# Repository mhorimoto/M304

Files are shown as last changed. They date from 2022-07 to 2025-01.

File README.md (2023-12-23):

# M304
UECS Controller Shield for Arduino MEGA I/F

## 1. PARTS

### 1-1. NIC

DIPタイプのW5500チップを使用したNICを使用する．

Tzt smart electronics USR-ES
https://ja.aliexpress.com/item/4000226162371.html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

### 1-2. LCD

20x4 Parallel connection (秋月コード P-10844)

## 2. Pin Assign

### 2-1. LCD (J1)

| I/O PIN | NAME | LCD PIN |
|:---:|---|:---:|
| | GND  | 1 |
| | Vdd  | 2 |
| | Vo | 3 |
| 37 | RS | 4 |
| 38 | R/W  | 5 |
| 39 | ENA  | 6 |
| 40 | DB0  | 7 |
| 41 | DB1  | 8 |
| 42 | DB2  | 9 |
| 43 | DB3  | 10 |
| 44 | DB4  | 11 |
| 45 | DB5  | 12 |
| 46 | DB6  | 13 |
| 47 | DB7  | 14 |
| | BL+  | 15 |
| | BL-  | 16 |

データピン８ピンすべて接続してある．

### 2-2. Relay OUT (J2)
リレー制御用のポートである．アクティブロー(負論理)である．

| J2 PIN | NAME |I/O PIN |
|:---:|---|:---:|
| 1 | RLY1 | 22 |
| 2 | RLY2 | 23 |
| 3 | RLY3 | 24 |
| 4 | RLY4 | 25 |
| 5 | RLY5 | 26 |
| 6 | RLY6 | 27 |
| 7 | RLY7 | 28 |
| 8 | RLY8 | 29 |
| 9 | Vdd  | +5V  |

リレー制御の自動・手動状態検知のための端子(STAT)はI/O PIN=31である.

|状態|D31の状態|
|:--:|:---:|
|自動| H |
|手動| L |

### 2-3. iM920 Interface (J3)
iM920用のインタフェースで3.3V駆動です.

| J3 PIN | NAME  | I/O PIN |
|:---:|---|:---:|
| 1 | RESET | D6 |
| 2 | BUSY  | D2 |
| 3 | GND | GND |
| 4 | Vcc | 3.3V  |
| 5 | TX | D19(Rx) |
| 6 | RX | D18(Tx) |
| 7 | STATUS| D5 |

### 2-4. GNSS(GPS) Interface (J4)
秋月電子通商のGNSSキット用．

| J4 PIN | NAME  | I/O PIN  |
|:---:|---|:---:|
| 1 | 1PPS  | D4 |
| 2 | RX | D14(Tx3) |
| 3 | TX | D15(Rx3) |
| 4 | GND | GND |
| 5 | Vcc | +5V |

### 2-5. Arrow Switch

アクティブローである．

| I/O PIN | 表示|回路図記号|
|:---:|:---:|:----:|
| 32 | 決定 (SW_ENTER)| SW6 |
| 33 |  ↑ (SW_A) | SW2 |
| 34 |  ↓ (SW_B) | SW3 |
| 35 |  ← (SW_C) | SW4 |
| 36 |  → (SW_D) | SW5 |

### 2-6. 選択
ADCに接続している．ロータリーエンコーダの代わりにADCの出力を得て選択する．

| I/O PIN | 表示 | 回路図記号 |
|:----:|:---:|:---:|
|  A15 | 選択(SELECTOR) | RV2 |

### 2-7. RESET
リセットボタンはArduino MEGAのRESETピンへ直結していると同時にNICのRESETピンにも接続されている．アクティブローである．

### 2-8. SAFEMODE Switch
UECSの初期設定を行う際に必要となるスイッチ．UARDECS_Libraryの既定値である

| I/O PIN | 表示 | 回路図記号 |
|:----:|:---:|:---:|
|  D3  | 初期設定(SAFEMODE) | SW7 |

### 2-9. JA pins (Analog ports)
以下のピン配置で3.3V用8ポート，5V用7ポートがある．
ソフトウェアで入出力の両用に使える．

| XH PIN | 意味 |
|:---:|:---|
| 1 | GND |
| 2 | CPUのAnalog port  |
| 3 | 電源 (3.3V or 5V)  |

コネクタとADCポートの関係

| PORT名 | 電圧 | I/O PIN |
|:-----:|:----:|:---:|
|  JA0  | 3.3V | A0 |
|  JA1  | 3.3V | A1 |
|  JA2  | 3.3V | A2 |
|  JA3  | 3.3V | A3 |
|  JA4  | 3.3V | A4 |
|  JA5  | 3.3V | A5 |
|  JA6  | 3.3V | A6 |
|  JA7  | 3.3V | A7 |
|  JA8  |  5V  | A8 |
|  JA9  |  5V  | A9 |
|  JA10 |  5V  | A10 |
|  JA11 |  5V  | A11 |
|  JA12 |  5V  | A12 |
|  JA13 |  5V  | A13 |
|  JA14 |  5V  | A14 |

### 2-10. JD pins (Digital ports)
以下のピン配置で7ポートある．ソフトウェアで入出力を切り替えられる．

| XH PIN | 意味 |
|:---:|:---|
| 1 | GND |
| 2 | CPUのDigital port  |

コネクタとDIOポートの関係

| PORT名 | I/O PIN |
|:-----:|:---:|
|  JD7  | D7 |
|  JD8  | D8 |
|  JD9  | D9 |
|  JD10 | D10 |
|  JD11 | D11 |
|  JD12 | D12 |
|  JD13 | D13 |

### 2-11. UART (JX2)
外部の装置とUART接続するためのポートが準備されている．
ポート名はJX2．電圧レベルは5V．接続先の送受関係は，2ピンに対象体のRxを3ピンにTxを接続する．

| XH PIN番号 | I/O PIN |
|:---:|:---:|
| 1 | GND |
| 2 | D16 (Tx2) |
| 3 | D17 (Rx2) |

### 2-12. TEST Pad
独自にテストを行う際の独立したDIO pinのパッド．

| Pad名 | I/O PIN |
|:-----:|:---:|
| JD30  | D30 |
| JD48  | D48 |
| JD49  | D49 |

### 2-13. I2C Devices

標準で搭載されているI2Cデバイスは以下の通り．

| Address | 名称 |
|:---:|:---|
| 0x50 | EEPROM AT24C256 |
| 0x68 | RTC DS1307 |

* EEPROM
AT24C256 を使用している．32kBytesの容量がある．
* RTC (Address=0x68)
DS1307を使用してる．(DS1307RTC)

https://stackedit.io/app#

## 3.Software

### 3-1. AT24C256 EEPROM

データの保存を行う他に重要な役割がある．

UECS-IDとMACアドレスを以下のアドレスに記録する．MSB first，Big endianにて記録する．

|  Address | Data |
|:---:|:---|
| 00H〜05H | UECS-ID |
| 06H〜0BH | MAC Address |
| 0CH〜1FH | Reserved |
| 20H〜7FFFH | Data |

* UECS-ID: 10100C00000B
* MAC Address: 02:A2:73:0B:xx:xx

### 3-2. M304_Library

M304_Libraryは，M304を使用する際に初期化やポート名を決定してくれるヘッダファイルと若干の関数がまとめられたファイル．
現状では，Arduino-IDE(arduino-cli)が使用できるディレクトリにコピーして使う．
将来的には，このディレクトリから分離されて，Arduino-IDEなどのライブラリ管理から管理できるようにする．
同時にUARDECS_MEGAとの整合も図る．

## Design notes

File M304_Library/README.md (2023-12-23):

# M304 Common

M304を使用する、汎用ソフトウェアライブラリ

## DISPLAY関連
### PAGE WRITE 機能
20x4のLCD画面をフラットに使用して書き換える。
20x4のメモリエリア(MEM20x4)を全体として使用して、遅いけれど全体を１回で書き込むルーティン。

### LINE WRITE 機能
MEM20x4の中を変更しつつライン単位で出力する。
PAGE WRITEよりも高速。

### CHAR WRITE 機能
MEM20x4の中を変更しつつ文字単位で出力する。
変更する文字の位置(アドレス)を指定して１文字単位で出力する。

## CROSS KEY SWITCH関連
### SIFモード
Start Input Fast モード

関数がコールされたときの入力の状態を返す。

### LIモード
Line Input モード

関数がコールされたら、決定、戻る、のボタンが押されるまで内部で入力処理を行う。

* 数値Aモード

VRによって数値を返す。map()を用いて下限上限を決める事ができる。

* 数値Dモード

上下キーを用いて数値を設定して返す。

## EEPROM関連

## RTC関連

## Ethernet関連
基本的にDHCPによる自動設定にする。IPアドレスなどのネットワーク情報はLCD画面に表示することが出来るのでDHCPで受信しても大丈夫。
* Broadcastに関しては、ネットワーク内でBroadcastするようにした。
具体的には、192.168.11.0/24のネットワークでは、192.168.11.255/24がブロードキャストアドレスとして適用する。また、172.16.0.0/16の場合には、172.16.255.255/16をブロードキャストアドレスとして適用する。他のケースもbitmaskに合わせて正確なブロードキャストを行う。

DNS
## GPS/GNSS関連

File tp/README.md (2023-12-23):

# Test Programs (tp)

M304 を単体動作させて機能を確認するためのプログラムです．

## tp001

LCDの動作確認を行うプログラム

## tp002

矢印キーおよび選択ボリュームの動作確認を行うプログラム

## tp003

選択ボリュームの出力値 0〜1023 を 0〜255 にまるめて，その値を元にリレーを動作させる．
すなわち，8個あるリレーをボリューム出力値に合わせてMake/Breakさせる．

## tp004

I2C EEPROMの動作確認を行うプログラム．  
実体は，ardeeprom (https://github.com/mhorimoto/ardeeprom.git) である．

## tp005

Ethernetを用いたLAN接続動作確認を行うプログラム

http://www.holly-linux.com/whoami/

へアクセスして，自局のIPアドレスを表示します．DHCPサービスでローカルIPが必要になります．

## tp006

RTCを用いた時刻表示プログラム

* DS1307RTC Library (https://github.com/PaulStoffregen/DS1307RTC.git)
* Time Library (https://github.com/PaulStoffregen/Time)

## tp007

GPSを用いた時刻表示ブログラム  
GPSで得られた時刻とRTCで得られた時刻を並行表示する．

## tp100

一連のTPシリーズとは異なりTinyGSMを用いてLTE回線経由でインターネットアクセスする．

* TinyGSM Library (https://github.com/vshymanskyy/TinyGSM.git)

WebClientを試す．

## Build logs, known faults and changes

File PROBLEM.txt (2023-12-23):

問題点

# CrossSwitch
* CrossSwitchのチャタリングがある。ソフトウェアで吸収すべきかもしれないが、
ソフトウェアの容易さと容量問題からCRによる簡易なチャタリング防止回路が欲しい。

* VRによる連続量入力は、ロータリーエンコーダにすべきだった。
VRの初期位置により既存入力値が変動してしまうのはよくない。
例えば、0〜255の範囲における既存入力値が50だったとして、VRの位置が
右に振り切っていた場合、入力値選択の開始は255から始まってしまう。
50から右に回すと増えていき、左に回すと減る。という人間的な感覚に追従できない。
そのため、CrossSwitchのUP/DOWNボタンを使うことになる。50から100へ変更する時、
50回ボタンを押すのは辛いので、連続量入力にしたい。

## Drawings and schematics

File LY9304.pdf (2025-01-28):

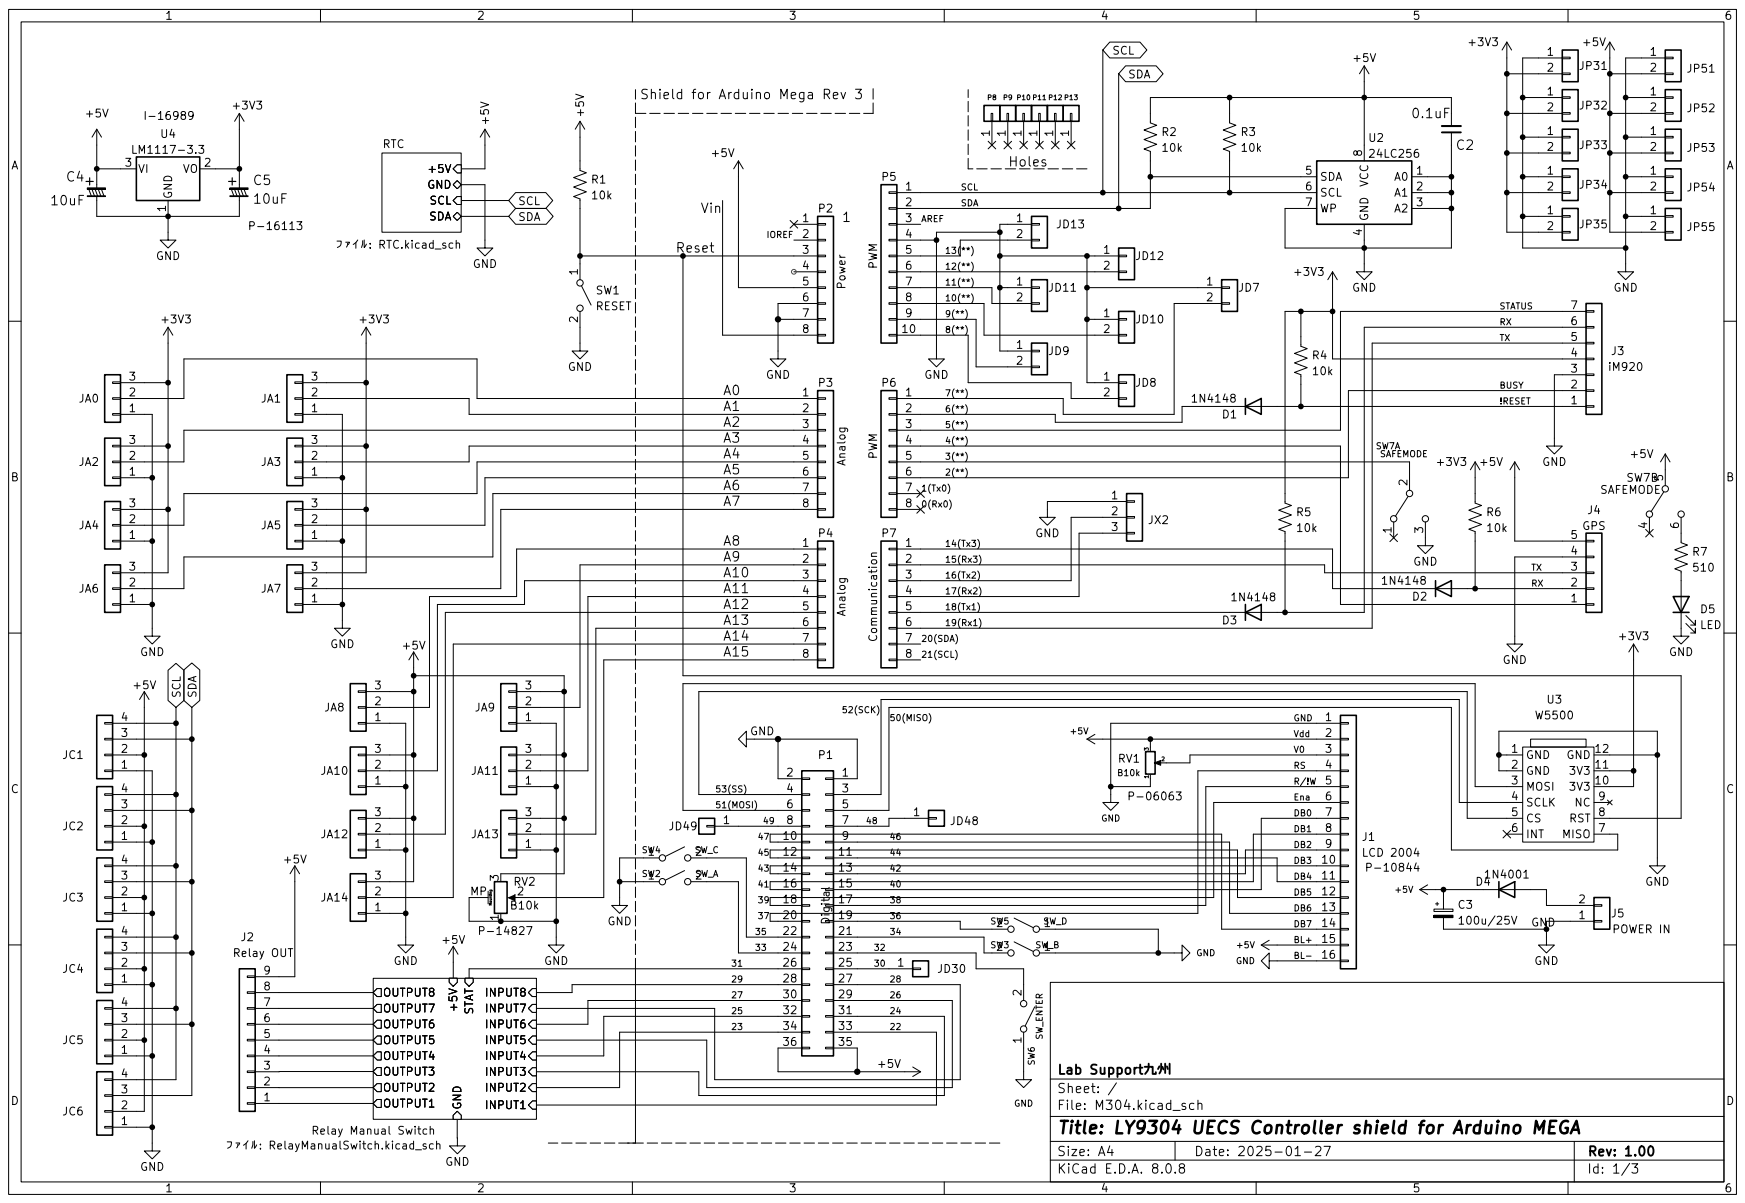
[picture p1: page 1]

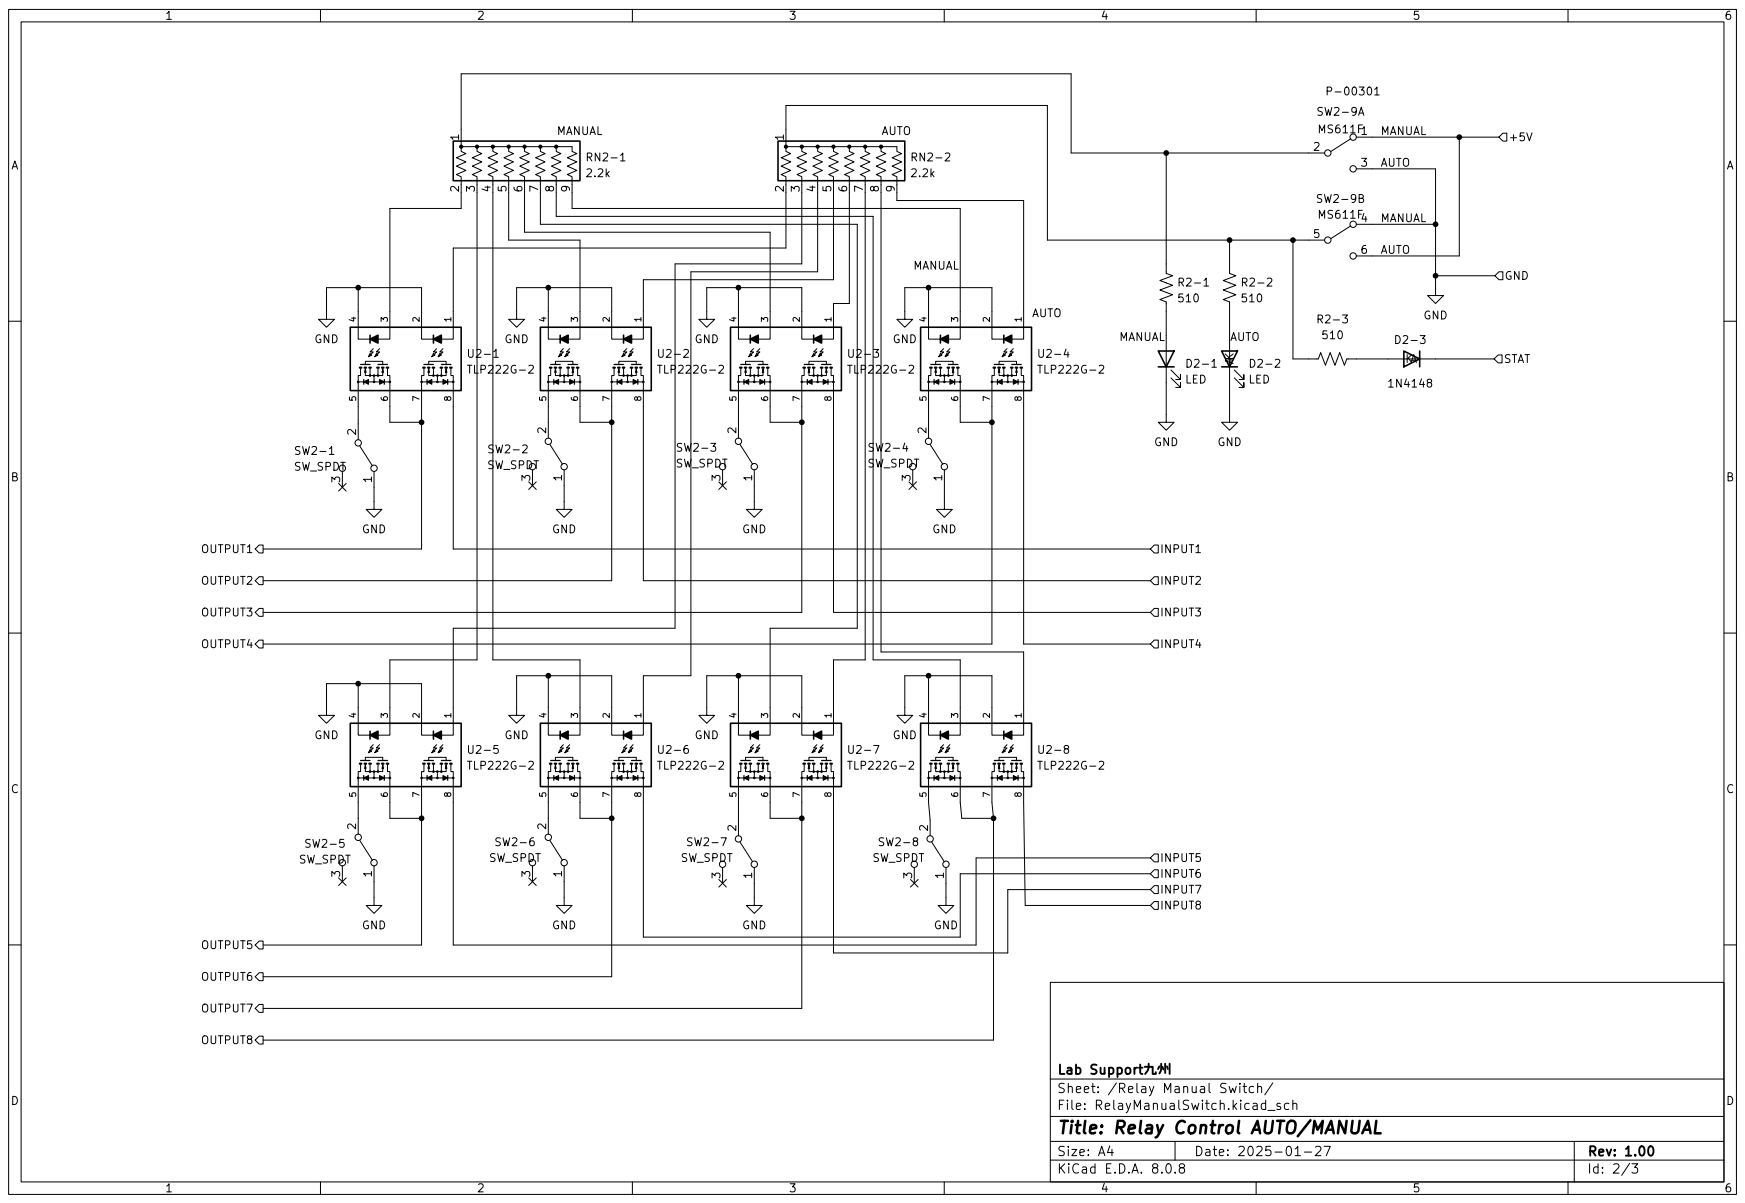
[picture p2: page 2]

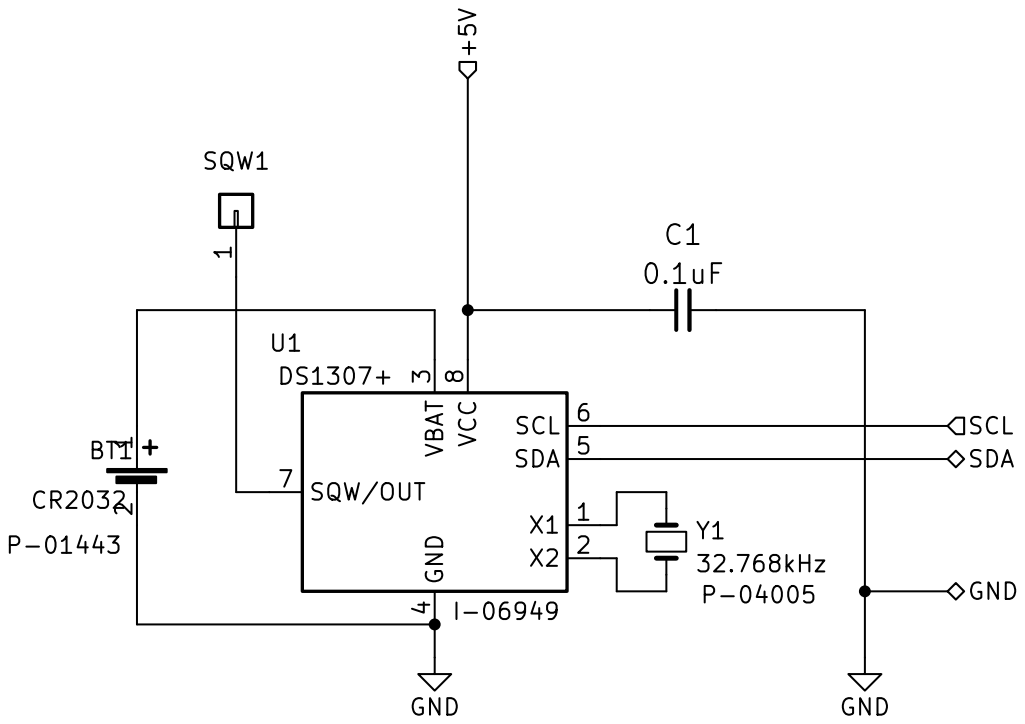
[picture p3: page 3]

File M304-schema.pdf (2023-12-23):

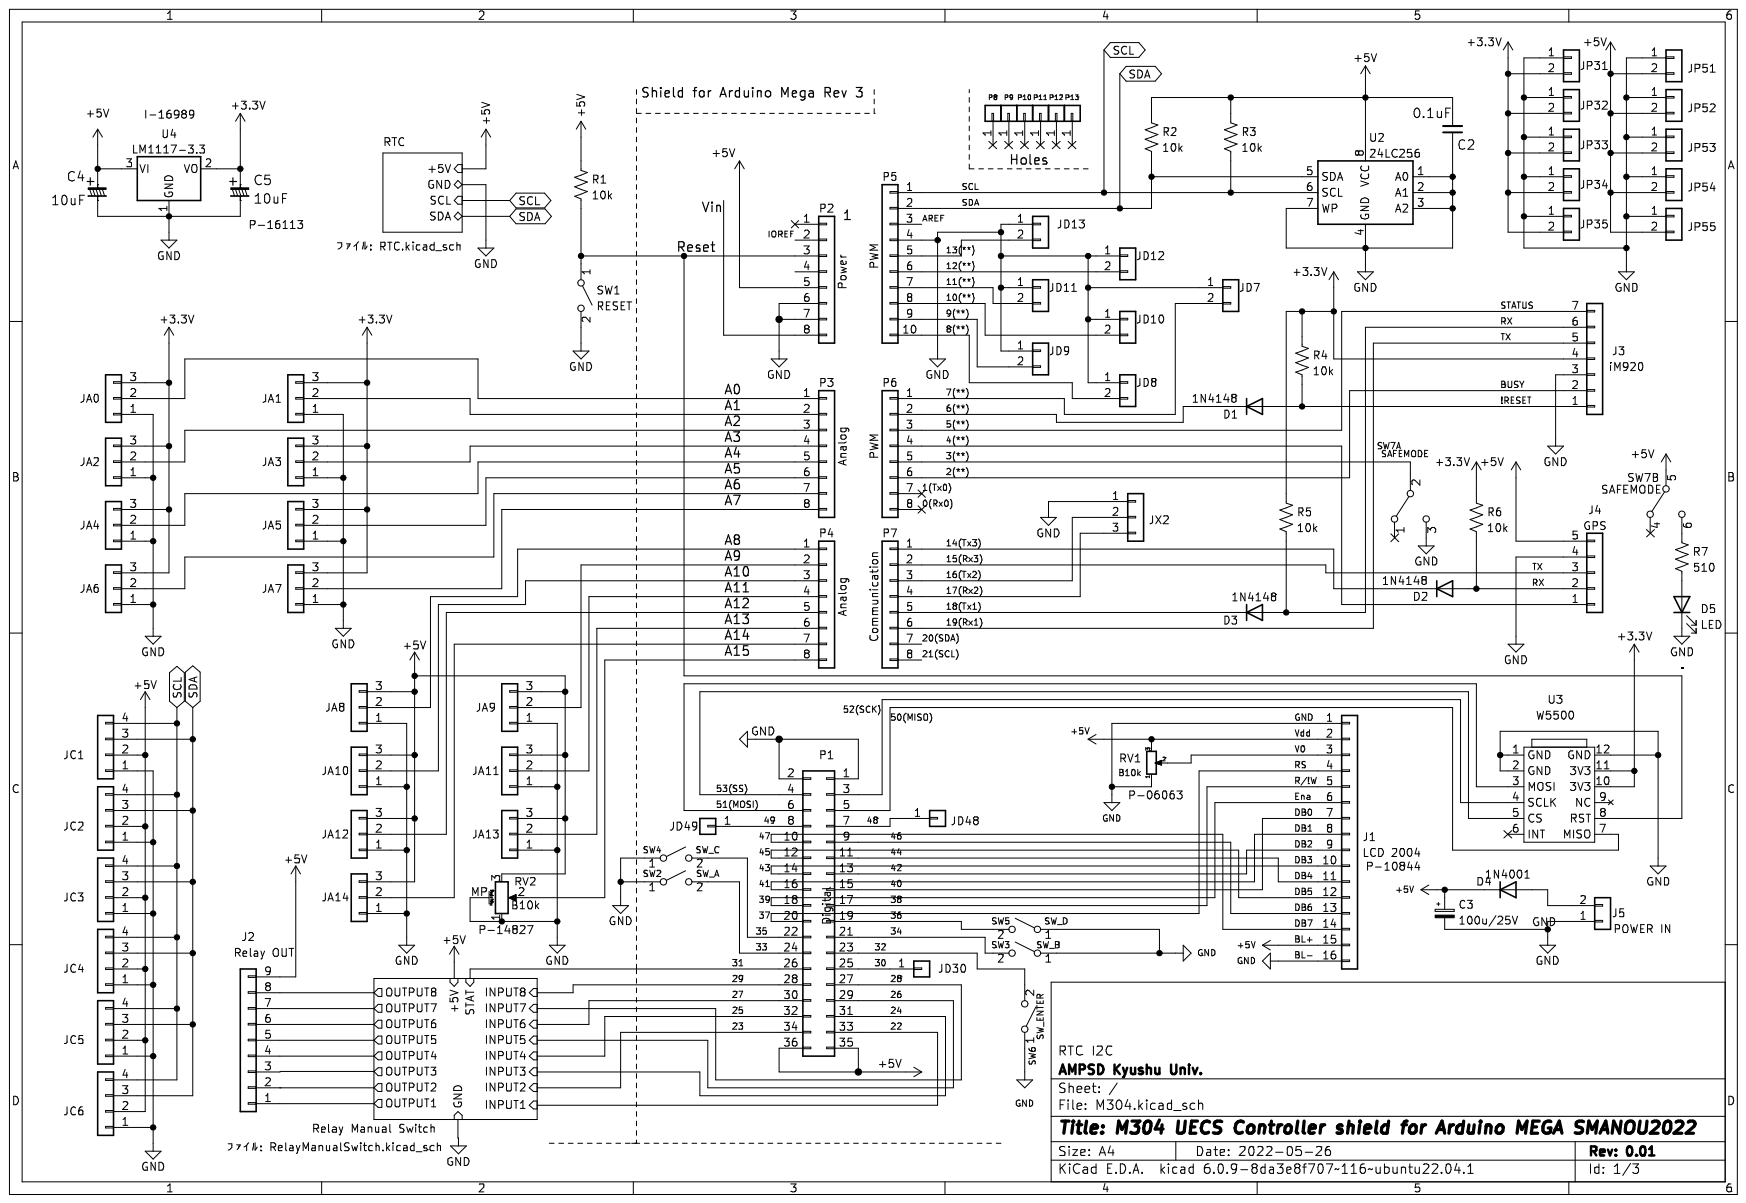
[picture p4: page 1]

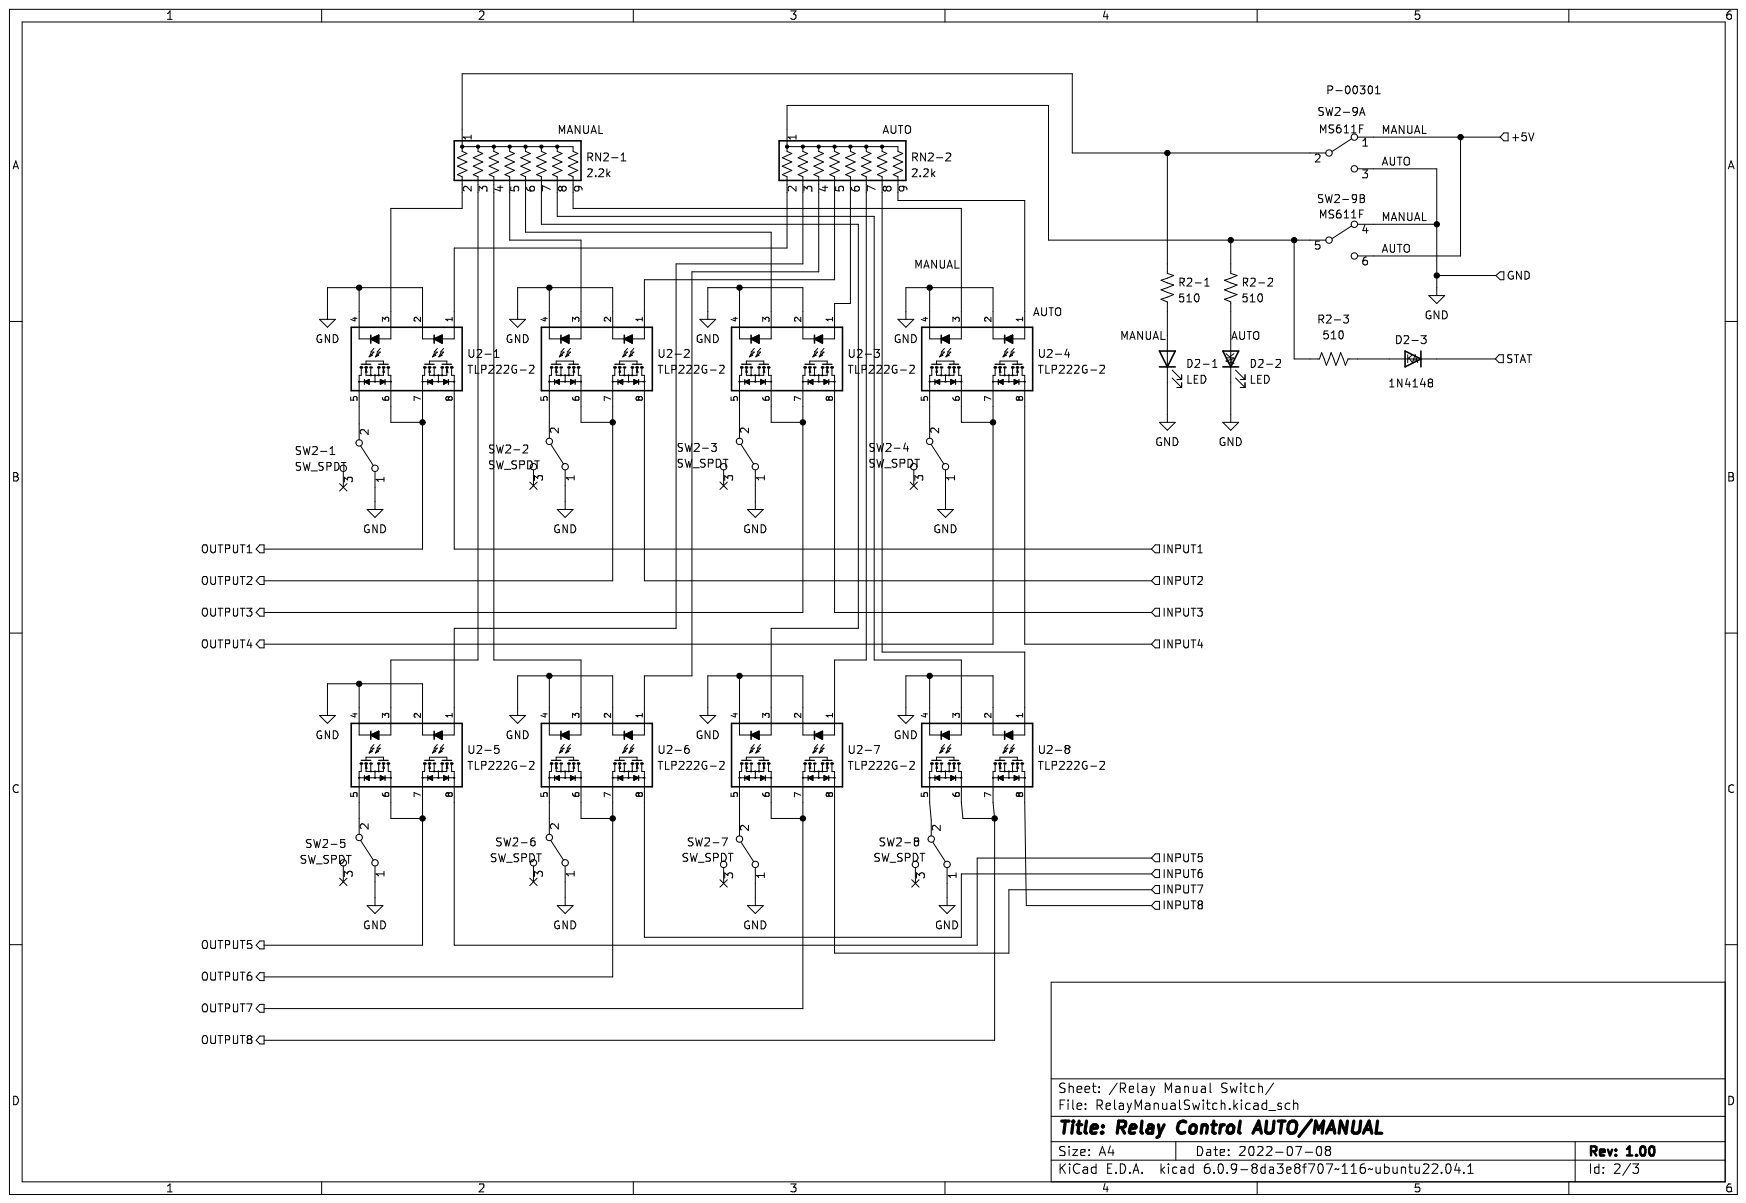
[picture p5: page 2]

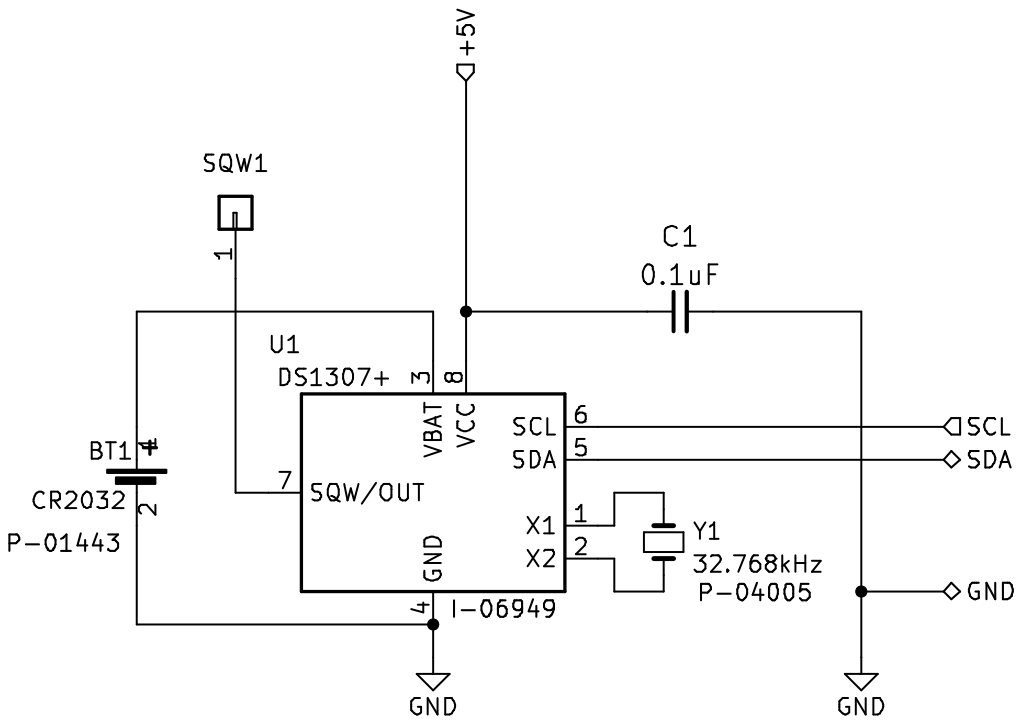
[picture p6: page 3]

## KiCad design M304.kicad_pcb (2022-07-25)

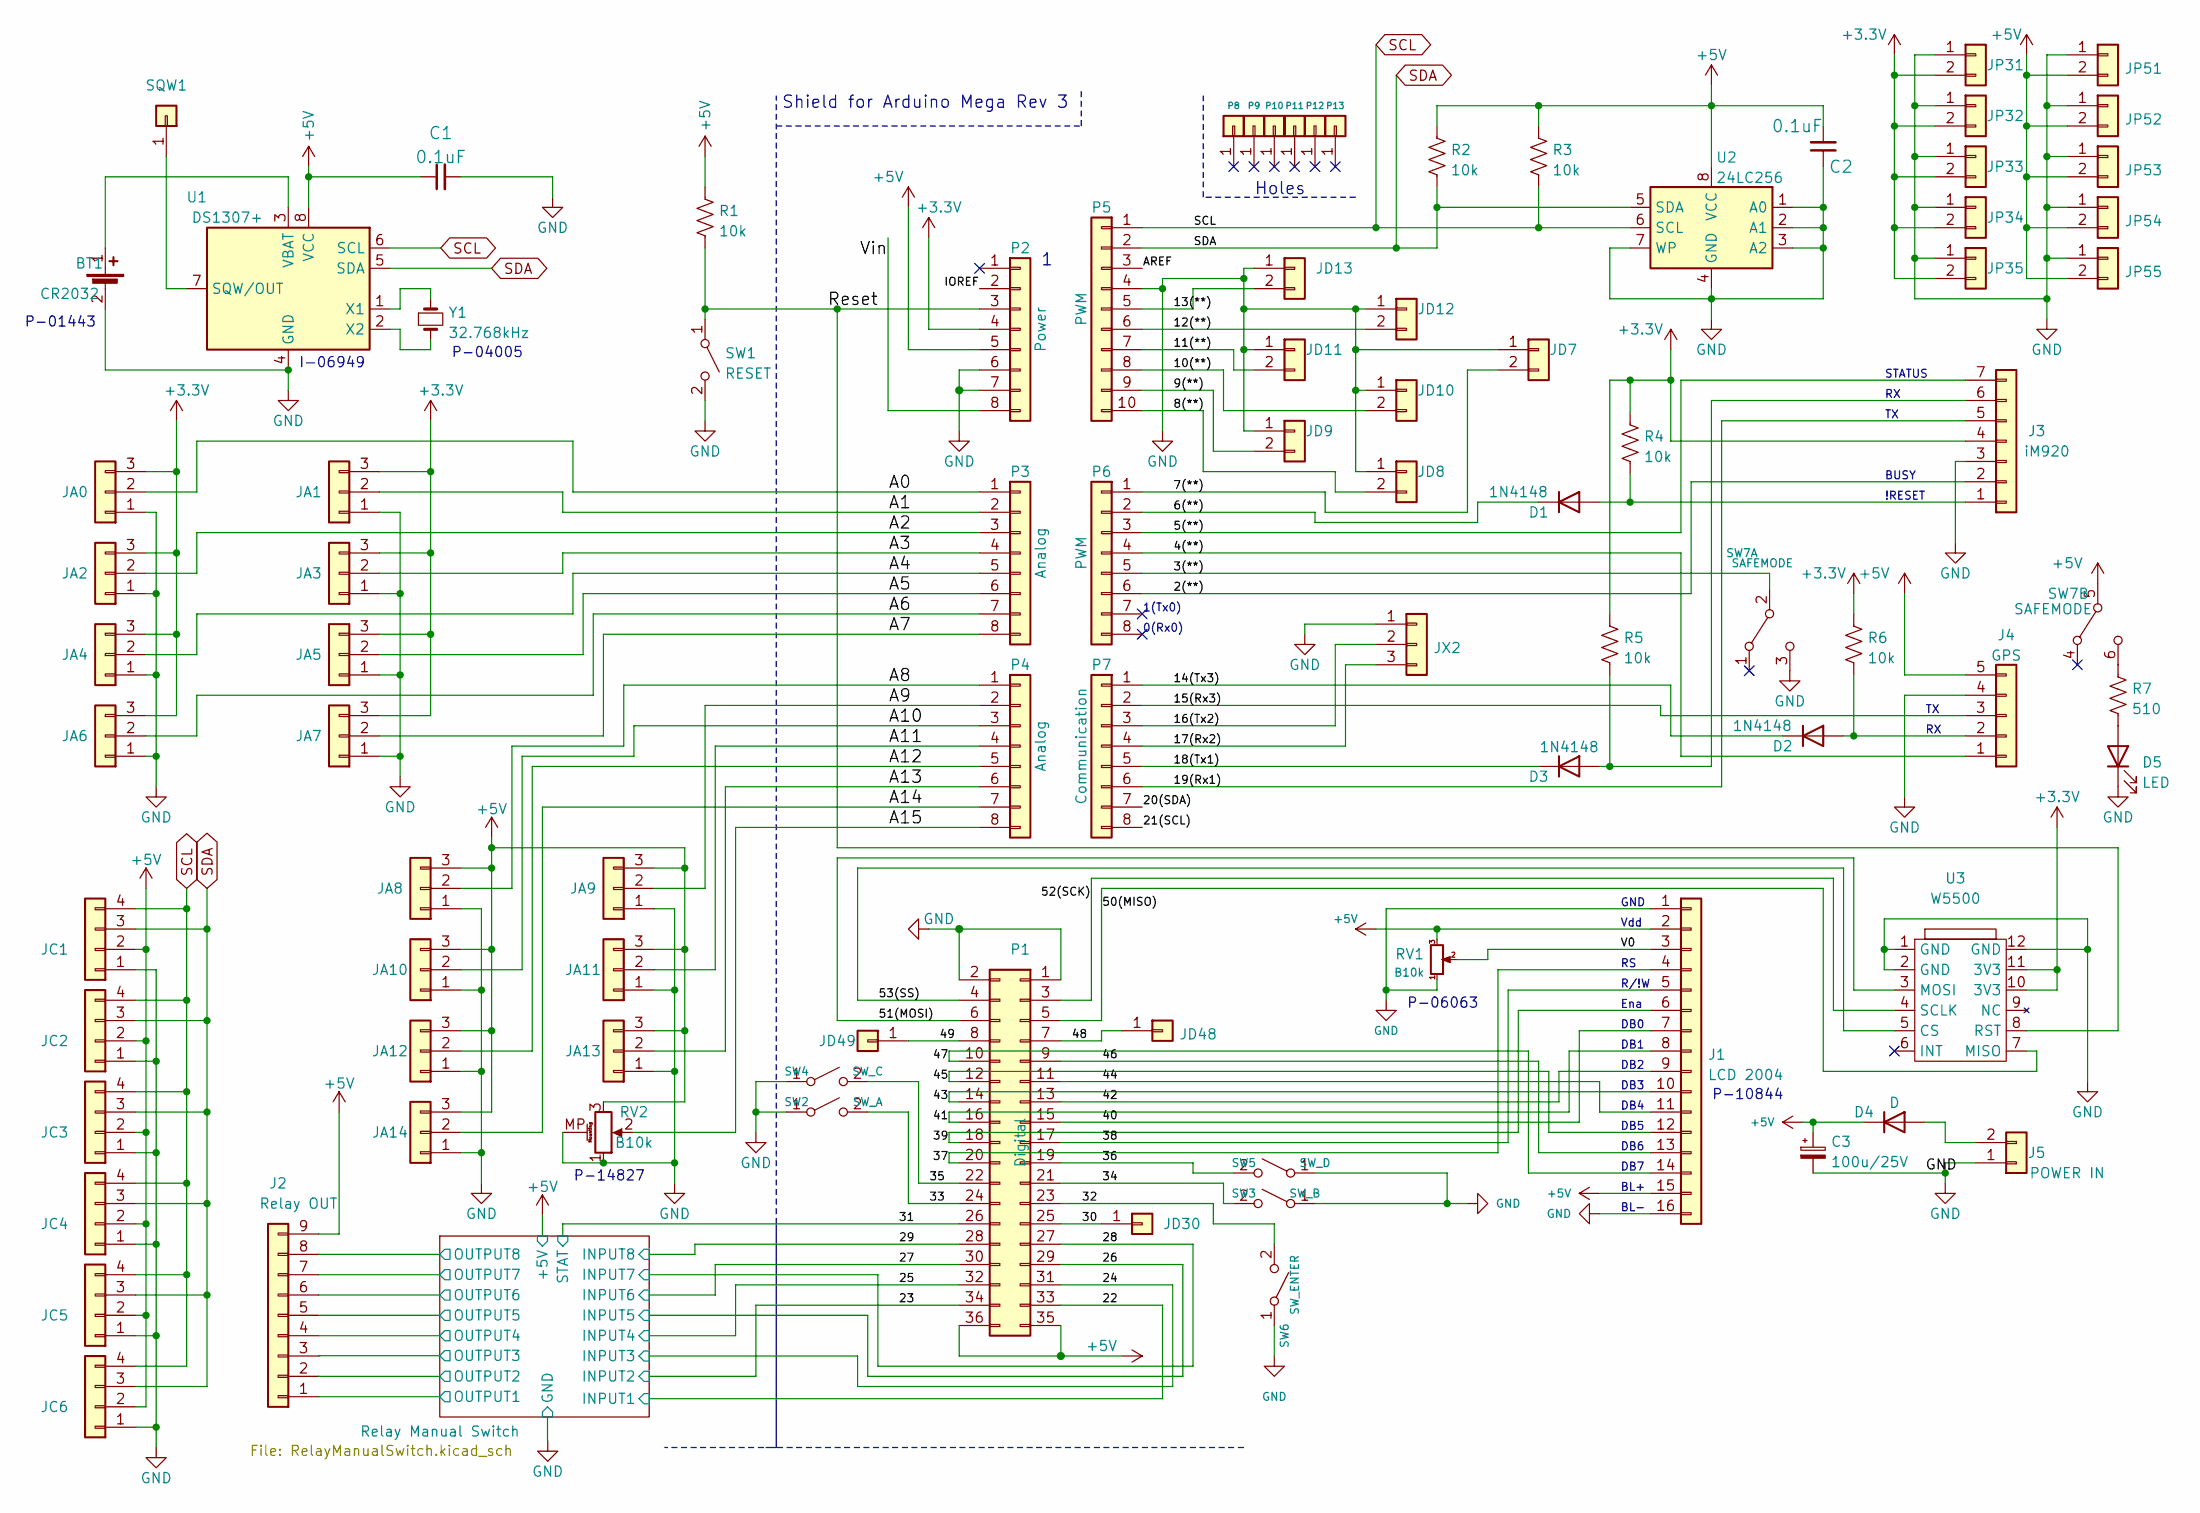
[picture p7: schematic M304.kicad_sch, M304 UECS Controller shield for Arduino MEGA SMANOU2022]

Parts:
BT1: CR2032; CH74-2032LF
C1, C2: 0.1uF; C_Disc_D3.0mm_W2.0mm_P2.50mm
C3: 100u/25V; CP_Radial_D5.0mm_P2.00mm
D1, D2, D3: 1N4148; D_DO-35_SOD27_P7.62mm_Horizontal
D4: D; D_DO-35_SOD27_P10.16mm_Horizontal
D5: LED; LED_D3.0mm
J1: LCD 2004; PinSocket_1x16_P2.54mm_Vertical
J2: Relay OUT; JST_XH_B9B-XH-A_1x09_P2.50mm_Vertical
J3: iM920; JST_XH_B7B-XH-A_1x07_P2.50mm_Vertical
J4: GPS; JST_XH_B5B-XH-A_1x05_P2.50mm_Vertical
J5: POWER IN; JST_VH_B2P-VH_1x02_P3.96mm_Vertical
JA0, JA1, JA2, JA3, JA4, JA5, JA6, JA7, JA8, JA9, JA10, JA11, JA12, JA13, JA14: Conn_01x03; JST_XH_B3B-XH-A_1x03_P2.50mm_Vertical
JC1, JC2, JC3, JC4, JC5, JC6: Conn_01x04; JST_XH_B4B-XH-A_1x04_P2.50mm_Vertical
JD7, JD8, JD9, JD10, JD11, JD12, JD13: Conn_01x02; JST_XH_B2B-XH-A_1x02_P2.50mm_Vertical
JD30, JD48, JD49: Conn_01x01; Pin_D0.9mm_L10.0mm_W2.4mm_FlatFork
JP31, JP32, JP33, JP34, JP35, JP51, JP52, JP53, JP54, JP55: Conn_01x02; JST_XH_B2B-XH-A_1x02_P2.50mm_Vertical
JX2: Conn_01x03; JST_XH_B3B-XH-A_1x03_P2.50mm_Vertical
P1: Digital; PinHeader_2x18_P2.54mm_Vertical
P2: Power; PinHeader_1x08_P2.54mm_Vertical
P3, P4: Analog; PinHeader_1x08_P2.54mm_Vertical
P5: PWM; PinHeader_1x10_P2.54mm_Vertical
P6: PWM; PinHeader_1x08_P2.54mm_Vertical
P7: Communication; PinHeader_1x08_P2.54mm_Vertical
P8, P9, P10, P11, P12, P13: CONN_01X01; Arduino_1pin
R1, R2, R3, R4, R5, R6: 10k; R_Axial_DIN0207_L6.3mm_D2.5mm_P7.62mm_Horizontal
R7: 510; R_Axial_DIN0207_L6.3mm_D2.5mm_P7.62mm_Horizontal
RV1: B10k; Potentiometer_Runtron_RM-065_Vertical
RV2: B10k; Potentiometer_Alps_RK09K_Single_Vertical
SQW1: Conn_01x01; Pin_D0.9mm_L10.0mm_W2.4mm_FlatFork
SW1: RESET; TVDT18-050
SW2: SW_A; TVDT18-050
SW3: SW_B; TVDT18-050
SW4: SW_C; TVDT18-050
SW5: SW_D; TVDT18-050
SW6: SW_ENTER; TVDT18-050
SW7: SAFEMODE; 2MD1T2B4M2QNS
U1: DS1307+; DIP-8_W7.62mm_LongPads
U2: 24LC256; DIP-8_W7.62mm_LongPads
U3: W5500
Y1: 32.768kHz; Crystal_C26-LF_D2.1mm_L6.5mm_Horizontal

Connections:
+3V3: J3.4, JA0.3, JA1.3, JA2.3, JA3.3, JA4.3, JA5.3, JA6.3, JA7.3, JP31.2, JP32.2, JP33.2, JP34.2, JP35.2, P2.4, R4.1, R5.1, R6.1, U3.10 (3V3), U3.11 (3V3)
+5V: C1.1, C2.2, C3.1, D4.1 (K), J1.2, J1.15, J2.9, J4.5, JA8.3, JA9.3, JA10.3, JA11.3, JA12.3, JA13.3, JA14.3, JC1.2, JC2.2, JC3.2, JC4.2, JC5.2, JC6.2, JP51.2, JP52.2, JP53.2, JP54.2, JP55.2, P1.35, P1.36, P2.5, R1.2, R2.1, R3.1, RV1.3, RV2.3, SW7.5 (B), U1.8 (VCC), U2.8 (VCC); also elsewhere on the board
/2(**): J3.2, P6.6
/3(**): P6.5, SW7.2 (B)
/4(**): J4.1, P6.4
/5(**): J3.7, P6.3
/6(**): D1.1 (K), P6.2
/7(**): JD7.2, P6.1
/8(**): JD8.2, P5.10
/9(**): JD9.2, P5.9
/10(**): JD10.2, P5.8
/11(**): JD11.2, P5.7
/12(**): JD12.2, P5.6
/13(**): JD13.2, P5.5
/14(Tx3): D2.1 (K), P7.1
/15(Rx3): J4.3, P7.2
/16(Tx2): JX2.2, P7.3
/17(Rx2): JX2.3, P7.4
/18(Tx1): D3.1 (K), P7.5
/19(Rx1): J3.5, P7.6
/20(SDA): P7.7
/21(SCL): P7.8
/22: P1.33; also elsewhere on the board
/23: P1.34; also elsewhere on the board
/24: P1.31; also elsewhere on the board
/25: P1.32; also elsewhere on the board
/26: P1.29; also elsewhere on the board
/27: P1.30; also elsewhere on the board
/28: P1.27; also elsewhere on the board
/29: P1.28; also elsewhere on the board
/30: JD30.1, P1.25
/31: P1.26; also elsewhere on the board
/32: P1.23, SW6.2 (B); also elsewhere on the board
/33: P1.24, SW2.2 (B)
/34: P1.21, SW3.2 (B)
/35: P1.22, SW4.2 (B)
/36: P1.19, SW5.2 (B)
/37: J1.4, P1.20
/38: J1.5, P1.17
/39: J1.6, P1.18
/40: J1.7, P1.15
/41: J1.8, P1.16
/42: J1.9, P1.13
/43: J1.10, P1.14
/44: J1.11, P1.11
/45: J1.12, P1.12
/46: J1.13, P1.9
/47: J1.14, P1.10
/48: JD48.1, P1.7
/49: JD49.1, P1.8
/50(MISO): P1.5, U3.7 (MISO)
/51(MOSI): P1.6, U3.3 (MOSI)
/52(SCK): P1.3, U3.4 (SCLK)
/53(SS): P1.4, U3.5 (CS)
/A0: JA0.2, P3.1
/A1: JA1.2, P3.2
/A2: JA2.2, P3.3
/A3: JA3.2, P3.4
/A4: JA4.2, P3.5
/A5: JA5.2, P3.6
/A6: JA6.2, P3.7
/A7: JA7.2, P3.8
/A8: JA8.2, P4.1
/A9: JA9.2, P4.2
/A10: JA10.2, P4.3
/A11: JA11.2, P4.4
/A12: JA12.2, P4.5
/A13: JA13.2, P4.6
/A14: JA14.2, P4.7
/A15: P4.8, RV2.2
/AREF: P5.3
/IOREF: P2.2
/Relay Manual Switch/OUTPUT1: J2.1; also elsewhere on the board
/Relay Manual Switch/OUTPUT2: J2.2; also elsewhere on the board
/Relay Manual Switch/OUTPUT3: J2.3; also elsewhere on the board
/Relay Manual Switch/OUTPUT4: J2.4; also elsewhere on the board
/Relay Manual Switch/OUTPUT5: J2.5; also elsewhere on the board
/Relay Manual Switch/OUTPUT6: J2.6; also elsewhere on the board
/Relay Manual Switch/OUTPUT7: J2.7; also elsewhere on the board
/Relay Manual Switch/OUTPUT8: J2.8; also elsewhere on the board
/Reset: P2.3, R1.1, SW1.1 (A), U3.8 (RST)
/V0: J1.3, RV1.2
/Vin: P2.8
GND: BT1.2 (-), C1.2, C2.1, C3.2, D5.1 (K), J1.1, J1.16, J3.3, J4.4, J5.1, JA0.1, JA1.1, JA2.1, JA3.1, JA4.1, JA5.1, JA6.1, JA7.1, JA8.1, JA9.1, JA10.1, JA11.1, JA12.1, JA13.1, JA14.1, JC1.1, JC2.1, JC3.1, JC4.1, JC5.1, JC6.1, JD7.1, JD8.1, JD9.1, JD10.1, JD11.1, JD12.1, JD13.1, JP31.1, JP32.1, JP33.1, JP34.1, JP35.1, JP51.1, JP52.1, JP53.1, JP54.1, JP55.1, JX2.1, P1.1, P1.2, P2.6, P2.7, P5.4, RV1.1, RV2.1, RV2.MP (MountPin), SW1.2 (B), SW2.1 (A), SW3.1 (A), SW4.1 (A), SW5.1 (A), SW6.1 (A), U1.4 (GND), U2.1 (A0), U2.2 (A1), U2.3 (A2), U2.4 (GND), U2.7 (WP), U3.1 (GND), U3.2 (GND), U3.12 (GND); also elsewhere on the board
unnamed: BT1.1 (+), U1.3 (VBAT)
unnamed: D1.2 (A), J3.1, R4.2
unnamed: D2.2 (A), J4.2, R6.2
unnamed: D3.2 (A), J3.6, R5.2
unnamed: D4.2 (A), J5.2
unnamed: D5.2 (A), R7.2
unnamed: R7.1, SW7.6 (C)
unnamed: SQW1.1, U1.7 (SQW/OUT)
unnamed: U1.1 (X1), Y1.1
unnamed: U1.2 (X2), Y1.2 (1)
SCL: JC1.4, JC2.4, JC3.4, JC4.4, JC5.4, JC6.4, P5.1, R3.2, U1.6 (SCL), U2.6 (SCL)
SDA: JC1.3, JC2.3, JC3.3, JC4.3, JC5.3, JC6.3, P5.2, R2.2, U1.5 (SDA), U2.5 (SDA)

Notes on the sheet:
DB5
P-10844
DB4
Ena
DB6
0(Rx0)
DB3
Vdd
BUSY
DB0
P-01443
R/!W
P-06063
DB1
GND
P-14827
I-06949
1(Tx0)
P-04005
Holes
BL+
STATUS
DB2
DB7
!RESET
BL-
Shield for Arduino Mega Rev 3

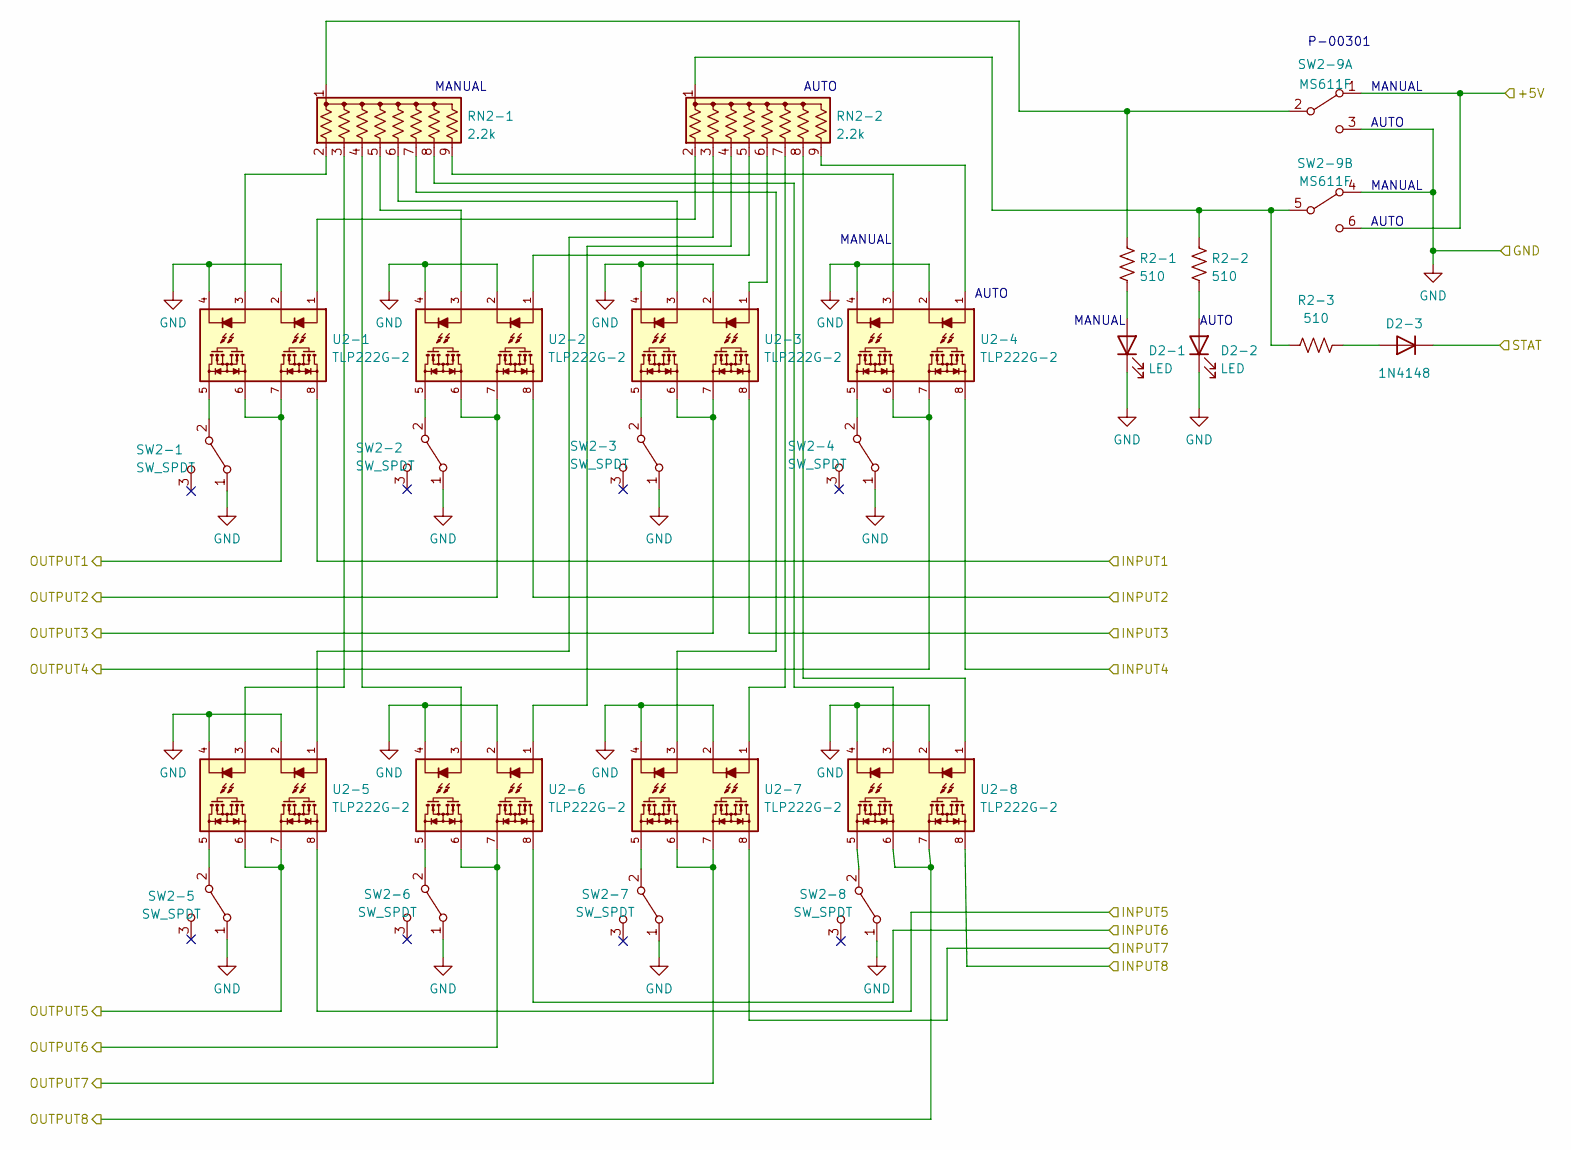
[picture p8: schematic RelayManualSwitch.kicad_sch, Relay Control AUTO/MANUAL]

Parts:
D2-1, D2-2: LED; LED_D3.0mm
D2-3: 1N4148; D_DO-35_SOD27_P7.62mm_Horizontal
R2-1, R2-2, R2-3: 510; R_Axial_DIN0207_L6.3mm_D2.5mm_P7.62mm_Horizontal
RN2-1, RN2-2: 2.2k; R_Array_SIP9
SW2-1, SW2-2, SW2-3, SW2-4, SW2-5, SW2-6, SW2-7, SW2-8: SW_SPDT; 2MS1T1B4M2QES
SW2-9: MS611F; 2MD1T2B4M2QNS
U2-1, U2-2, U2-3, U2-4, U2-5, U2-6, U2-7, U2-8: TLP222G-2; TLP222A-2

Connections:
+5V: SW2-9.1 (A), SW2-9.6 (C); also elsewhere on the board
/22: U2-1.8; also elsewhere on the board
/23: U2-2.8; also elsewhere on the board
/24: U2-3.8; also elsewhere on the board
/25: U2-4.8; also elsewhere on the board
/26: U2-5.8; also elsewhere on the board
/27: U2-6.8; also elsewhere on the board
/28: U2-7.8; also elsewhere on the board
/29: U2-8.8; also elsewhere on the board
/31: D2-3.1 (K); also elsewhere on the board
/Relay Manual Switch/OUTPUT1: U2-1.6, U2-1.7; also elsewhere on the board
/Relay Manual Switch/OUTPUT2: U2-2.6, U2-2.7; also elsewhere on the board
/Relay Manual Switch/OUTPUT3: U2-3.6, U2-3.7; also elsewhere on the board
/Relay Manual Switch/OUTPUT4: U2-4.6, U2-4.7; also elsewhere on the board
/Relay Manual Switch/OUTPUT5: U2-5.6, U2-5.7; also elsewhere on the board
/Relay Manual Switch/OUTPUT6: U2-6.6, U2-6.7; also elsewhere on the board
/Relay Manual Switch/OUTPUT7: U2-7.6, U2-7.7; also elsewhere on the board
/Relay Manual Switch/OUTPUT8: U2-8.6, U2-8.7; also elsewhere on the board
GND: D2-1.1 (K), D2-2.1 (K), SW2-1.1 (A), SW2-2.1 (A), SW2-3.1 (A), SW2-4.1 (A), SW2-5.1 (A), SW2-6.1 (A), SW2-7.1 (A), SW2-8.1 (A), SW2-9.3 (C), SW2-9.4 (A), U2-1.2, U2-1.4, U2-2.2, U2-2.4, U2-3.2, U2-3.4, U2-4.2, U2-4.4, U2-5.2, U2-5.4, U2-6.2, U2-6.4, U2-7.2, U2-7.4, U2-8.2, U2-8.4; also elsewhere on the board
unnamed: D2-1.2 (A), R2-1.2
unnamed: D2-2.2 (A), R2-2.2
unnamed: D2-3.2 (A), R2-3.2
unnamed: R2-1.1, RN2-1.1 (common), SW2-9.2 (B)
unnamed: R2-2.1, R2-3.1, RN2-2.1 (common), SW2-9.5 (B)
unnamed: RN2-1.2 (R1), U2-1.3
unnamed: RN2-1.3 (R2), U2-5.3
unnamed: RN2-1.4 (R3), U2-6.3
unnamed: RN2-1.5 (R4), U2-2.3
unnamed: RN2-1.6 (R5), U2-3.3
unnamed: RN2-1.7 (R6), U2-7.3
unnamed: RN2-1.8 (R7), U2-8.3
unnamed: RN2-1.9 (R8), U2-4.3
unnamed: RN2-2.2 (R1), U2-1.1
unnamed: RN2-2.3 (R2), U2-5.1
unnamed: RN2-2.4 (R3), U2-6.1
unnamed: RN2-2.5 (R4), U2-2.1
unnamed: RN2-2.6 (R5), U2-3.1
unnamed: RN2-2.7 (R6), U2-7.1
unnamed: RN2-2.8 (R7), U2-8.1
unnamed: RN2-2.9 (R8), U2-4.1
unnamed: SW2-1.2 (B), U2-1.5
unnamed: SW2-2.2 (B), U2-2.5
unnamed: SW2-3.2 (B), U2-3.5
unnamed: SW2-4.2 (B), U2-4.5
unnamed: SW2-5.2 (B), U2-5.5
unnamed: SW2-6.2 (B), U2-6.5
unnamed: SW2-7.2 (B), U2-7.5
unnamed: SW2-8.2 (B), U2-8.5

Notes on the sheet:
AUTO
MANUAL
P-00301

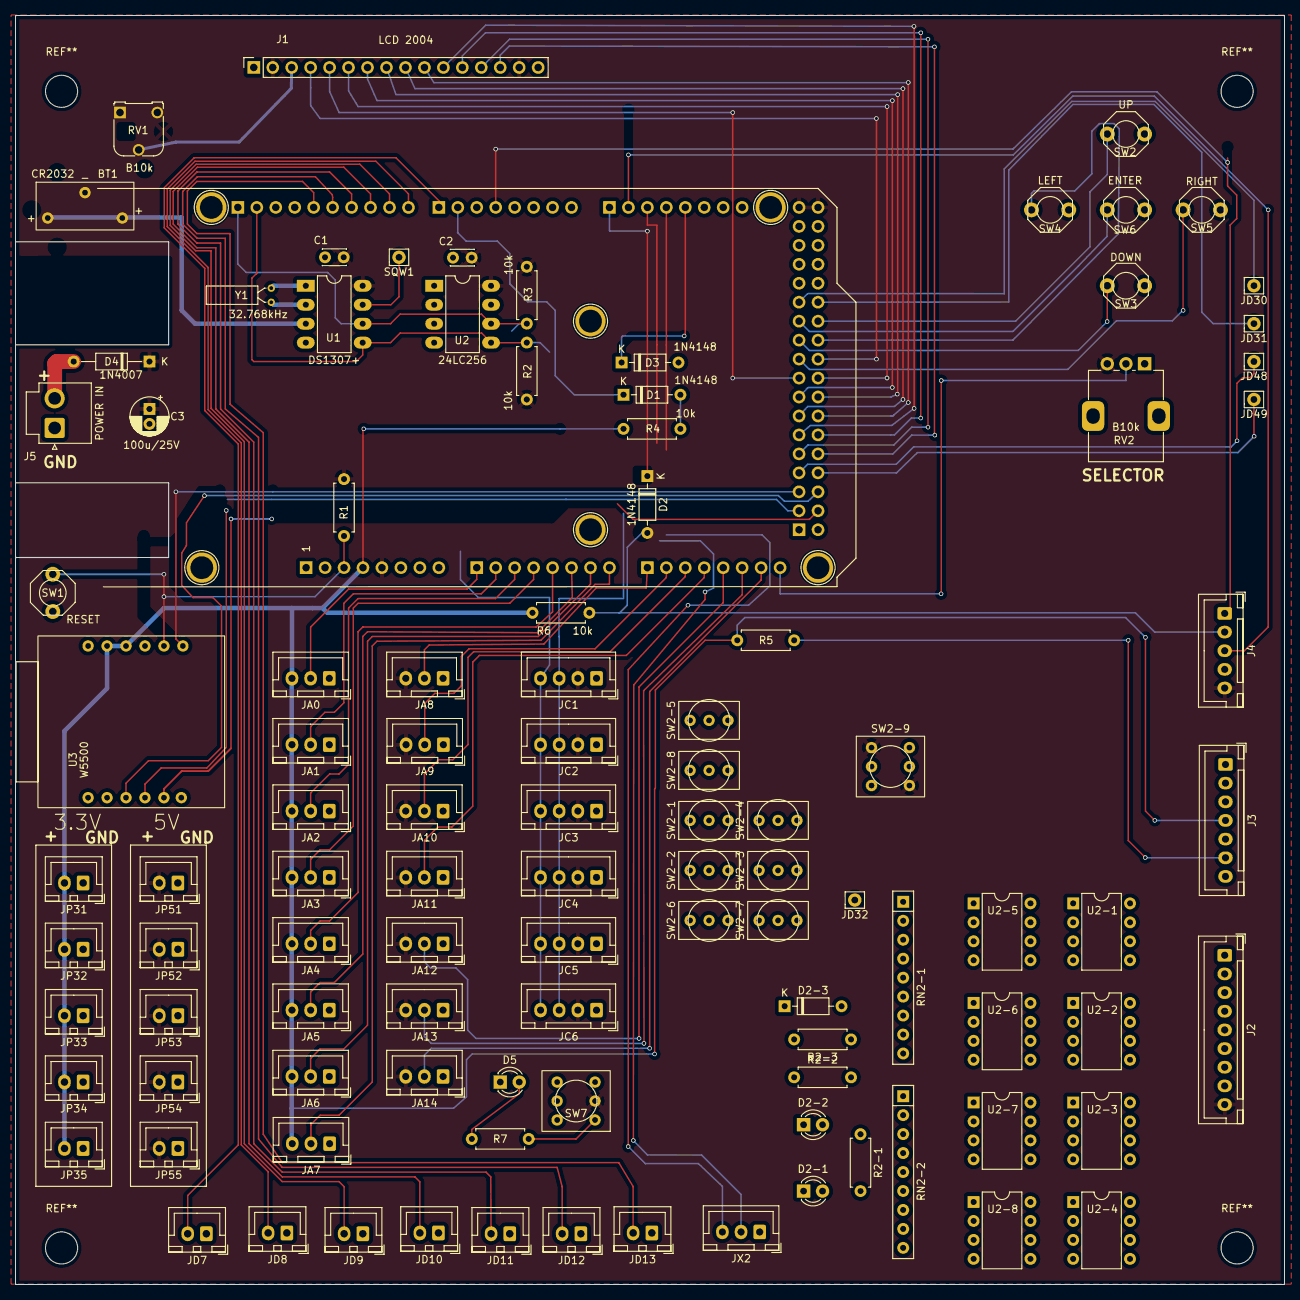
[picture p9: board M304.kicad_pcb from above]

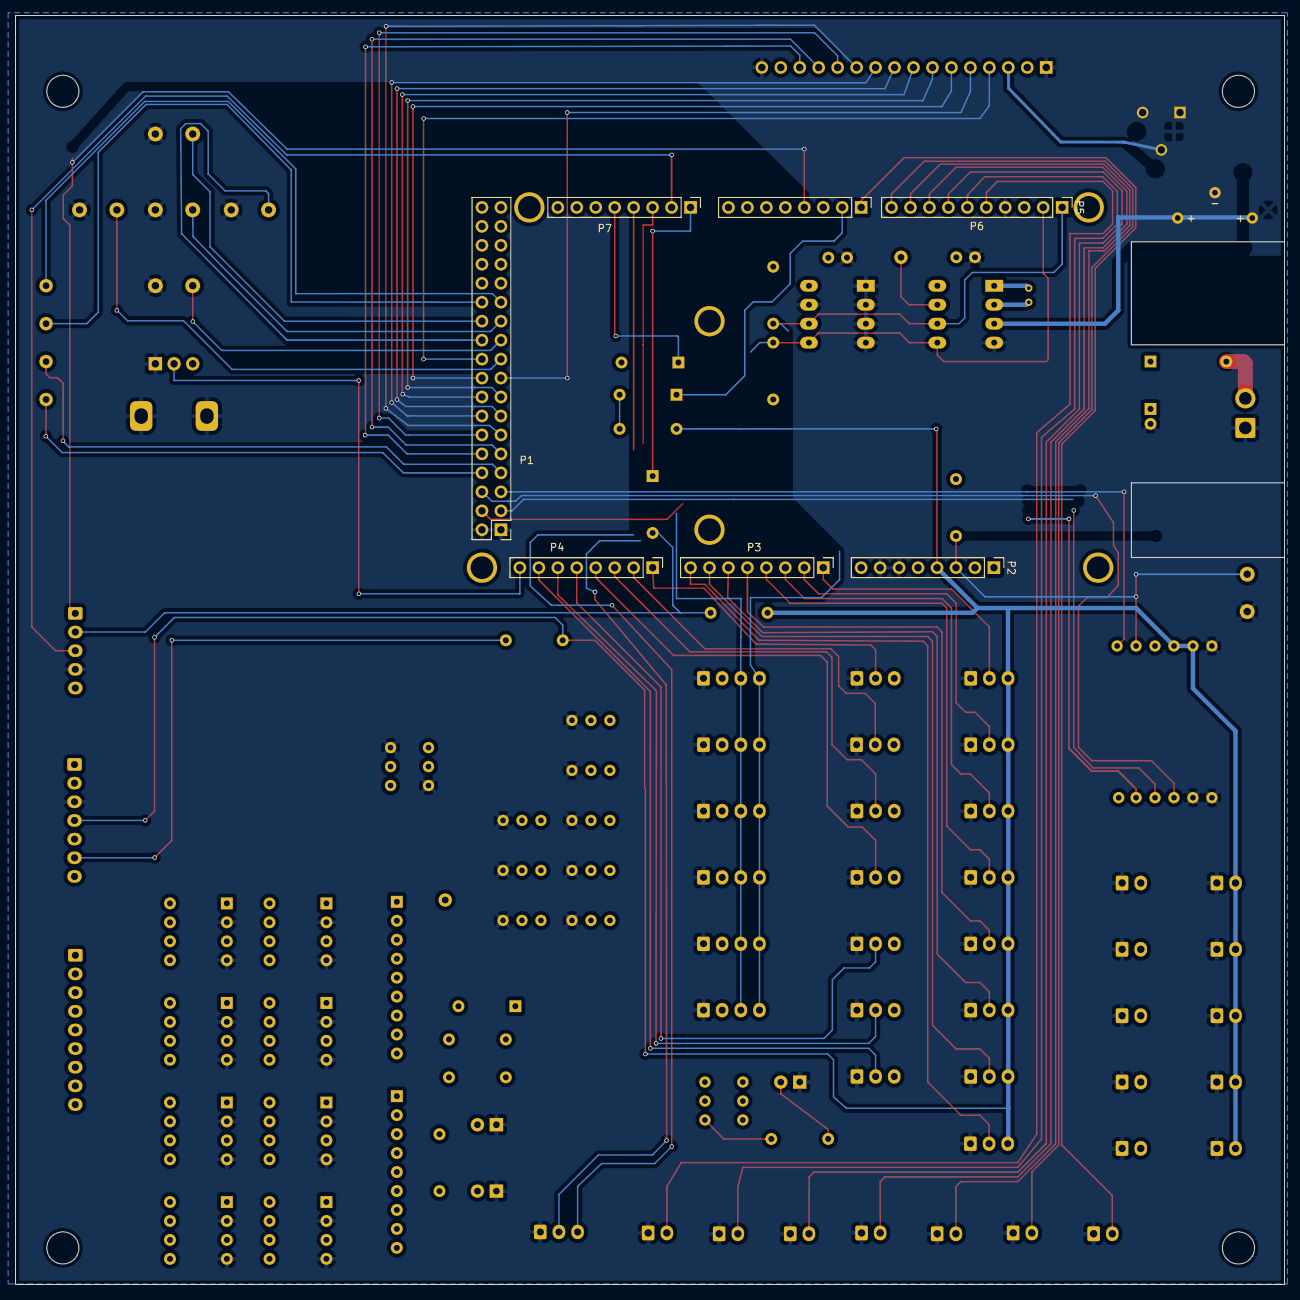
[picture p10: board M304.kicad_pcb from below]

Board: 2 copper layers, 170.0 x 170.0 mm, 117 parts (7 on the bottom side), 120 nets.

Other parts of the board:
JD31, JD32: Conn_01x01; Pin_D0.9mm_L10.0mm_W2.4mm_FlatFork

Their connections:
/31: JD31.1; also elsewhere on the board
/32: JD32.1; also elsewhere on the board

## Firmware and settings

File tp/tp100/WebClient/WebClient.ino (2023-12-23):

/**************************************************************
 *
 * This sketch connects to a website and downloads a page.
 * It can be used to perform HTTP/RESTful API calls.
 *
 * TinyGSM Getting Started guide:
 *   https://tiny.cc/tinygsm-readme
 *
 **************************************************************/

// Select your modem:
// #define TINY_GSM_MODEM_SIM800
// #define TINY_GSM_MODEM_SIM808
// #define TINY_GSM_MODEM_SIM868
// #define TINY_GSM_MODEM_SIM900
// #define TINY_GSM_MODEM_SIM7000
// #define TINY_GSM_MODEM_SIM7000SSL
// #define TINY_GSM_MODEM_SIM7080
// #define TINY_GSM_MODEM_SIM5360
// #define TINY_GSM_MODEM_SIM7600
// #define TINY_GSM_MODEM_UBLOX
#define TINY_GSM_MODEM_SARAR4
// #define TINY_GSM_MODEM_M95
// #define TINY_GSM_MODEM_BG96
// #define TINY_GSM_MODEM_A6
// #define TINY_GSM_MODEM_A7
// #define TINY_GSM_MODEM_M590
// #define TINY_GSM_MODEM_MC60
// #define TINY_GSM_MODEM_MC60E
// #define TINY_GSM_MODEM_ESP8266
// #define TINY_GSM_MODEM_XBEE
// #define TINY_GSM_MODEM_SEQUANS_MONARCH

// Set serial for debug console (to the Serial Monitor, default speed 115200)
#define SerialMon Serial

// Set serial for AT commands (to the module)
// Use Hardware Serial on Mega, Leonardo, Micro
#ifndef __AVR_ATmega328P__
#define SerialAT Serial2

// or Software Serial on Uno, Nano
#else
#include <SoftwareSerial.h>
SoftwareSerial SerialAT(2, 3);  // RX, TX
#endif

// Increase RX buffer to capture the entire response
// Chips without internal buffering (A6/A7, ESP8266, M590)
// need enough space in the buffer for the entire response
// else data will be lost (and the http library will fail).
#if !defined(TINY_GSM_RX_BUFFER)
#define TINY_GSM_RX_BUFFER 650
#endif

// See all AT commands, if wanted
//#define DUMP_AT_COMMANDS

// Define the serial console for debug prints, if needed
#define TINY_GSM_DEBUG SerialMon

// Range to attempt to autobaud
// NOTE:  DO NOT AUTOBAUD in production code.  Once you've established
// communication, set a fixed baud rate using modem.setBaud(#).
#define GSM_AUTOBAUD_MIN 9600
#define GSM_AUTOBAUD_MAX 115200

// Add a reception delay, if needed.
// This may be needed for a fast processor at a slow baud rate.
// #define TINY_GSM_YIELD() { delay(2); }

// Uncomment this if you want to use SSL
#define USE_SSL

// Define how you're planning to connect to the internet.
// This is only needed for this example, not in other code.
#define TINY_GSM_USE_GPRS true
#define TINY_GSM_USE_WIFI false

// set GSM PIN, if any
#define GSM_PIN ""

// Your GPRS credentials, if any
const char apn[]      = "4gn.jp";
const char gprsUser[] = "roke@moba";
const char gprsPass[] = "rokemoba";

// Your WiFi connection credentials, if applicable
const char wifiSSID[] = "YourSSID";
const char wifiPass[] = "YourWiFiPass";

// Server details
const char server[] = "www.holly-linux.com";
const char resource[] = "/whoami.php";
//const char server[]   = "vsh.pp.ua";
//const char resource[] = "/TinyGSM/logo.txt";

#include <TinyGsmClient.h>

// Just in case someone defined the wrong thing..
#if TINY_GSM_USE_GPRS && not defined TINY_GSM_MODEM_HAS_GPRS
#undef TINY_GSM_USE_GPRS
#undef TINY_GSM_USE_WIFI
#define TINY_GSM_USE_GPRS false
#define TINY_GSM_USE_WIFI true
#endif
#if TINY_GSM_USE_WIFI && not defined TINY_GSM_MODEM_HAS_WIFI
#undef TINY_GSM_USE_GPRS
#undef TINY_GSM_USE_WIFI
#define TINY_GSM_USE_GPRS true
#define TINY_GSM_USE_WIFI false
#endif

#ifdef DUMP_AT_COMMANDS
#include <StreamDebugger.h>
StreamDebugger debugger(SerialAT, SerialMon);
TinyGsm        modem(debugger);
#else
TinyGsm        modem(SerialAT);
#endif

#ifdef USE_SSL
TinyGsmClientSecure client(modem);
const int           port = 443;
#else
TinyGsmClient  client(modem);
const int      port = 80;
#endif

void setup() {
  // Set console baud rate
  SerialMon.begin(115200);
  delay(10);

  // !!!!!!!!!!!
  // Set your reset, enable, power pins here
  // !!!!!!!!!!!

  SerialMon.println("Wait...");

  // Set GSM module baud rate
  TinyGsmAutoBaud(SerialAT, GSM_AUTOBAUD_MIN, GSM_AUTOBAUD_MAX);
  // SerialAT.begin(9600);
  delay(6000);

  // Restart takes quite some time
  // To skip it, call init() instead of restart()
  SerialMon.println("Initializing modem...");
  modem.restart();
  //modem.init();

  String modemInfo = modem.getModemInfo();
  SerialMon.print("Modem Info: ");
  SerialMon.println(modemInfo);

#if TINY_GSM_USE_GPRS
  // Unlock your SIM card with a PIN if needed
  if (GSM_PIN && modem.getSimStatus() != 3) { modem.simUnlock(GSM_PIN); }
#endif
}

void loop() {
#if TINY_GSM_USE_WIFI
  // Wifi connection parameters must be set before waiting for the network
  SerialMon.print(F("Setting SSID/password..."));
  if (!modem.networkConnect(wifiSSID, wifiPass)) {
    SerialMon.println(" fail");
    delay(10000);
    return;
  }
  SerialMon.println(" success");
#endif

#if TINY_GSM_USE_GPRS && defined TINY_GSM_MODEM_XBEE
  // The XBee must run the gprsConnect function BEFORE waiting for network!
  modem.gprsConnect(apn, gprsUser, gprsPass);
#endif

  SerialMon.print("Waiting for network...");
  if (!modem.waitForNetwork()) {
    SerialMon.println(" fail");
    delay(10000);
    return;
  }
  SerialMon.println(" success");

  if (modem.isNetworkConnected()) { SerialMon.println("Network connected"); }

#if TINY_GSM_USE_GPRS
  // GPRS connection parameters are usually set after network registration
  SerialMon.print(F("Connecting to "));
  SerialMon.print(apn);
  if (!modem.gprsConnect(apn, gprsUser, gprsPass)) {
    SerialMon.println(" fail");
    delay(10000);
    return;
  }
  SerialMon.println(" success");

  if (modem.isGprsConnected()) { SerialMon.println("GPRS connected"); }
#endif

  SerialMon.print("Connecting to ");
  SerialMon.println(server);
  if (!client.connect(server, port)) {
    SerialMon.println(" fail");
    delay(10000);
    return;
  }
  SerialMon.println(" success");

  // Make a HTTP GET request:
  SerialMon.println("Performing HTTP GET request...");
  client.print(String("GET ") + resource + " HTTP/1.1\r\n");
  client.print(String("Host: ") + server + "\r\n");
  client.print("Connection: close\r\n\r\n");
  client.println();

  uint32_t timeout = millis();
  while (client.connected() && millis() - timeout < 10000L) {
    // Print available data
    while (client.available()) {
      char c = client.read();
      SerialMon.print(c);
      timeout = millis();
    }
  }
  SerialMon.println();

  // Shutdown

  client.stop();
  SerialMon.println(F("Server disconnected"));

#if TINY_GSM_USE_WIFI
  modem.networkDisconnect();
  SerialMon.println(F("WiFi disconnected"));
#endif
#if TINY_GSM_USE_GPRS
  modem.gprsDisconnect();
  SerialMon.println(F("GPRS disconnected"));
#endif

  // Do nothing forevermore
  while (true) { delay(1000); }
}

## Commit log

2022-05-27 KiCAD開始
    [001.kicad_pcb, 001.kicad_sch]
2022-05-27 半分終了
    [001.kicad_sch]
2022-05-29 RTC追加
    [001.kicad_sch]
2022-06-02 Append RTC
    [001.kicad_sch]
2022-07-03 信号ラベルの見直し中
    [001.kicad_sch]
2022-07-05 回路だいたい出来た。
    [001.kicad_pcb, 001.kicad_sch]
2022-07-07 PCB layout
    [M304.kicad_pcb, M304.kicad_sch]
2022-07-07 Arduino MEGA pin direction change
    [M304.kicad_pcb, M304.kicad_sch]
2022-07-07 Photo coupler append
    [M304.kicad_sch, RelayManualSwitch.kicad_sch]
2022-07-09 階層基板化中
    [M304.kicad_sch, RelayManualSwitch.kicad_sch]
2022-07-13 RelayManualSwitch回路充実
    [M304.kicad_sch, RelayManualSwitch.kicad_sch]
2022-07-17 Mode STAT monitoring
    [M304.kicad_sch, RelayManualSwitch.kicad_sch]
2022-07-19 PCB Design start
    [M304.kicad_pcb, M304.kicad_sch, RelayManualSwitch.kicad_sch]
2022-07-19 PCB Design cont.
    [M304.kicad_pcb, M304.kicad_sch]
2022-07-20 コミット忘れ？
2022-07-20 PCB少し変更
    [M304.kicad_pcb]
2022-07-22 UECS/MANUAL 切り替え表示LED
    [M304.kicad_pcb, M304.kicad_sch, RelayManualSwitch.kicad_sch]
2022-07-22 PCB随分と考え中
    [M304.kicad_pcb, M304.kicad_sch, RelayManualSwitch.kicad_sch]
2022-07-24 PCB設計中
    [M304.kicad_pcb]
2022-07-24 print属性変更
2022-07-25 W5500周囲の変更
    [M304.kicad_pcb]
2022-07-26 部品リストにAKICODEを追加した
    [M304.kicad_sch]
2022-07-29 parts list 更新
    [M304.kicad_sch, RelayManualSwitch.kicad_sch]
2022-07-31 スイッチ周りの配線を残すのみ
    [M304.kicad_sch, RelayManualSwitch.kicad_sch]
2022-08-01 一応完成、粗熱を取る
    [M304.kicad_sch]
2022-08-01 シルク印刷を日本語化・スマ農塾向けだけ
2022-08-02 LCDの3Dイメージを追加とCAMOUTを出力しPCB屋さんで試す。
    [M304-B_Cu.gbr, M304-B_Mask.gbr, M304-B_Silkscreen.gbr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]
2022-08-02 3.3V三端子レギュレータを追加し、RTC回路を階層図面化
    [M304.kicad_sch, RTC.kicad_sch]
2022-08-03 部品リスト更新
    [M304.kicad_sch, RTC.kicad_sch]
2022-08-08 ガーバー出力・発注
    [M304-B_Cu.gbr, M304-B_Mask.gbr, M304-B_Silkscreen.gbr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]
2022-08-17 docs: Port and Pin assign
2022-08-18 docs: Append Port and Pin assign
2022-08-18 docs: feat: pin assign append and create tp
2022-08-18 docs: pin assign append
2022-08-24 tp002,tp003を追加
2022-08-28 prog: M304_Libraryの追加とTP004までの変更
2022-09-07 docs: I2Cアドレス追記
2022-10-12 feat: tp007追加
2022-11-21 docs: add schematic PDF
2022-11-25 feat: RTCとの組み合わせ
2022-11-30 feat: GPSモジュール初期化プログラム
2022-12-30 feat: tp008 cross switch subroutine
2023-03-16 docs:MAC Address sample
2023-04-01 docs: READMEを増やす
2023-04-19 prog: LCDなどのmethod追加
2023-05-03 prog: headerファイルにバージョンを反映させるようにしてコンパイルエラーを避けるようにした
2023-05-04 prog: IntWrite()の改良とヘッダにバージョンを記す
2023-05-08 prog: cmenuの追加など
2023-05-15 prog: モード値の変更
2023-12-23 ver: KiCAD version update
    [M304.kicad_sch, RTC.kicad_sch, RelayManualSwitch.kicad_sch]
2023-12-23 ver: KiCAD Version match
    [M304.kicad_sch, RTC.kicad_sch, RelayManualSwitch.kicad_sch]
2024-04-25 KiCAD Version 8.0
    [M304.kicad_sch, RTC.kicad_sch, RelayManualSwitch.kicad_sch]
2025-01-28 Lab Support九州 ヴァージョン
    [M304.kicad_sch, RTC.kicad_sch, RelayManualSwitch.kicad_sch]
